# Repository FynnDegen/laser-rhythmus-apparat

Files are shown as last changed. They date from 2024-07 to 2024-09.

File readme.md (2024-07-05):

# laser-rhythmus-apparat (lra)

## Vorraussetzungen

- PortAudio

## Bauteile

- 1x Mikrokontroller (Arduino UNO R4 Minima):
https://store.arduino.cc/collections/boards-modules/products/uno-r4-minima

- 5x Lasersensoren (VL53L0X):
https://www.amazon.de/AZDelivery-VL53L0X-Flight-kompatibel-Arduino/dp/B086TSNTFD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

- Kabel (weiblich-weiblich, weiblich-männlich, männlich-männlich je 40x):
https://www.amazon.de/Female-Female-Male-Female-Male-Male-Steckbr%C3%BCcken-Drahtbr%C3%BCcken-bunt/dp/B01EV70C78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

- 2x Steckbretter:
https://www.amazon.de/VoltMate-Breadboard-Steckbrett-Kontakten-Kompatibel/dp/B0CX8MMN6T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

## Arduino

Falls ein Fehler auf Linux ubuntu auftreten sollte:

https://support.arduino.cc/hc/en-us/articles/9005041052444-Fix-udev-rules-on-Linux#renesas

Wie angegeben die post_install.sh Datei von GitHub herunterladen und im Verzeichnis der Datei das Terminal öffnen.

Dem .sh Skript Ausführungsrechte erteilen

```
chmod +x ./post_install.sh
```

Die Datei ausführen

```
sudo ./post_install.sh
```

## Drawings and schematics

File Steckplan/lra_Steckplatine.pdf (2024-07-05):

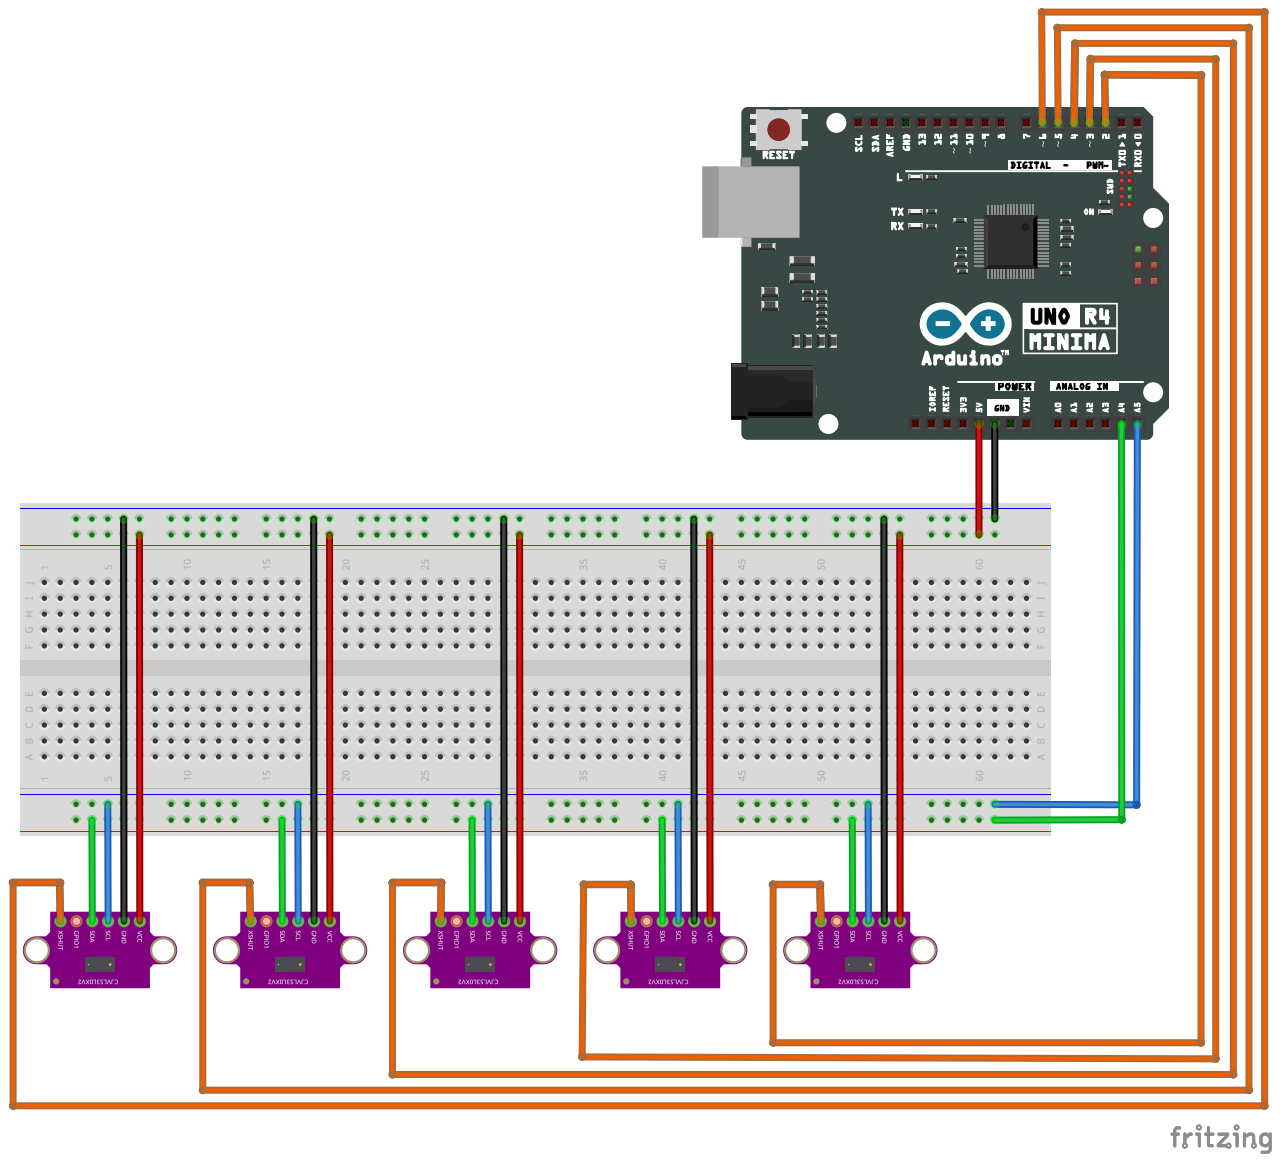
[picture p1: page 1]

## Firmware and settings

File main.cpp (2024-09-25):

#include <fcntl.h>
#include <termios.h>
#include <unistd.h>
#include <iostream>
#include <string.h>
#include <stdio.h>
#include <math.h>
#include <signal.h>
#include <random>

#include <portaudio.h>

#define MODE true

#define SAMPLE_RATE 44100
#define NUM_LASER 5

struct SineWaveData {
    double frequency = 0.0;
    double amplitude = 0.0;
    double phase = 0.0;
    bool isPlayed = false;
    short osc = 0;

    void increment() {
        phase += (2.0 * M_PI * frequency) / SAMPLE_RATE;
        if (phase >= 2.0 * M_PI) {
            phase -= 2.0 * M_PI;
        }
    }
};

int serialPort;

PaStream *stream;
SineWaveData data[NUM_LASER];

double oscillator(int oscNum, double phase) {
    switch(oscNum) {
        case 0:
            return sin(phase); // sine wave
        case 1:
            return (phase < 0.5) ? 0 : 1; // square wave
        case 2:
            return (2/M_PI)*asin(sin(phase)); // triangle wave
        case 3:
            return (cos(phase/2) < 0.0) ? (2/M_PI)*asin(sin(phase/2)) : (2/M_PI)*asin(cos((phase/2) - M_PI)); // sawtooth wave
        default:
            return 0.0;
    }
}

static int paCallback(const void *inputBuffer, void *outputBuffer, unsigned long framesPerBuffer, const PaStreamCallbackTimeInfo* timeInfo, PaStreamCallbackFlags statusFlags, void *userData) {
    float *out = (float*)outputBuffer;
    SineWaveData *data = (SineWaveData*)userData;
    
    for (unsigned long i = 0; i < framesPerBuffer; i++) {

        float audioOutput = 0;
        for(size_t i = 0; i < NUM_LASER; i++) {
            audioOutput += data[i].amplitude * oscillator(data[i].osc, data[i].phase);
        }
        audioOutput /= 3.75;
        *out++ = audioOutput;

        for(size_t i = 0; i < NUM_LASER; i++) {
            data[i].increment();
        }
    }
    return paContinue;
}

void checkErr(PaError err) {
    Pa_Terminate();
    std::cerr << "Fehler bei der Nutzung von PortAudio: " << Pa_GetErrorText(err) << std::endl;
    exit(-1);
}

int openSerialPort(const char* port) {
    int serialPort = open(port, O_RDONLY);

    if(serialPort < 0) {
        std::cerr << "Fehler beim Verbinden zum Arduino" << std::endl;
        exit(-1);
    }

    return serialPort;
}

void defaultMode() {

    data[0].frequency = 987.767; // h2
    data[1].frequency = 783.991; // g2
    data[2].frequency = 659.255; // e2
    data[3].frequency = 554.365; // cis2/des2
    data[4].frequency = 440.0;   // a1

    char read_buf[256];

    while(true) {
        memset(&read_buf, '\0', sizeof(read_buf));
        int num_bytes = read(serialPort, &read_buf, sizeof(read_buf));

        if(num_bytes < 0) {
            std::cerr << "Fehler beim Lesen vom Arduino" << std::endl;
            break;
        }

        std::string measurement = read_buf;
        if(measurement.find(":") != std::string::npos) {
            int laserIndex = measurement.at(1) - '0';
            int laser = std::stoi(measurement.substr(3));

            std::cout << laserIndex << " " << laser << std::endl;

            if(laser <= 720 && laser >= 60) {
                if(data[laserIndex].isPlayed) {
                    data[laserIndex].amplitude = std::max(0.5+((double)(rand() % 10)) / 100.0, data[laserIndex].amplitude-0.125);
                } else {
                    data[laserIndex].amplitude = 0.75;
                    data[laserIndex].isPlayed = true;
                }
            } else if((laser > 720 || laser < 60) && laser != 0) {
                data[laserIndex].amplitude = std::max(0.0, data[laserIndex].amplitude-0.075);
                data[laserIndex].isPlayed = false;
            }
        }
    }
}

void experimentalMode() {

    char read_buf[256];

    while(true) {
        memset(&read_buf, '\0', sizeof(read_buf));
        int num_bytes = read(serialPort, &read_buf, sizeof(read_buf));

        if(num_bytes < 0) {
            std::cerr << "Fehler beim Lesen vom Arduino" << std::endl;
            break;
        }

        std::string measurement = read_buf;
        if(measurement.find(":") != std::string::npos) {
            int laserIndex = measurement.at(1) - '0';
            int laser = std::stoi(measurement.substr(3));

            std::cout << laserIndex << " " << laser << std::endl;

            if(laser <= 720 && laser >= 60) {
                data[laserIndex].frequency = laser + 160;
            } else if((laser > 720 || laser < 60) && laser != 0) {
                data[laserIndex].frequency = 0;
            }
        }
    }
}

void signalHandler(int signum) {
    if(PaError err = Pa_StopStream(stream) != paNoError) {
        checkErr(err);
    }
    if(PaError err = Pa_CloseStream(stream) != paNoError) {
        checkErr(err);
    }
    if(PaError err = Pa_Terminate() != paNoError) {
        checkErr(err);
    }
    close(serialPort);
    std::cout << "\nLRA beendet" << std::endl;
    exit(0);
}

int main() {
    // Signal handler
    signal(SIGINT, signalHandler);

    // Serial port
    serialPort = openSerialPort("/dev/ttyACM0");

    //PortAudio
    if(PaError err = Pa_Initialize() != paNoError) {
        checkErr(err);
    }

    if( PaError err = Pa_OpenDefaultStream(&stream, 0, 1, paFloat32, SAMPLE_RATE, 256, paCallback, &data) != paNoError) {
        checkErr(err);
    }
    if(PaError err = Pa_StartStream(stream) != paNoError) {
        checkErr(err);
    }

    if(MODE) {
        defaultMode();
    } else {
        experimentalMode();
    }
}

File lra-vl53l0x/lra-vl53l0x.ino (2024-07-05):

#include "Adafruit_VL53L0X.h"

#define NUM_SENSORS 5

// address we will assign if dual sensor is present
const uint8_t LOX_ADDRESS[NUM_SENSORS] = {
    0x30, 0x31, 0x32, 0x33, 0x34
};

// set the pins to shutdown
const uint8_t SHT_LOX[NUM_SENSORS] = {
    2, 3, 4, 5, 6
};

// objects for the vl53l0x
Adafruit_VL53L0X lox[NUM_SENSORS];

// this holds the measurement
VL53L0X_RangingMeasurementData_t measure[NUM_SENSORS];

/*
    Reset all sensors by setting all of their XSHUT pins low for delay(10), then set all XSHUT high to bring out of reset
    Keep sensor #1 awake by keeping XSHUT pin high
    Put all other sensors into shutdown by pulling XSHUT pins low
    Initialize sensor #1 with lox.begin(new_i2c_address) Pick any number but 0x29 and it must be under 0x7F. Going with 0x30 to 0x3F is probably OK.
    Keep sensor #1 awake, and now bring sensor #2 out of reset by setting its XSHUT pin high.
    Initialize sensor #2 with lox.begin(new_i2c_address) Pick any number but 0x29 and whatever you set the first sensor to
 */
void setID() {
    // all reset
    for(int i = 0; i < NUM_SENSORS; i++) {
        digitalWrite(SHT_LOX[i], LOW);
    }
    delay(10);
    // all unreset
    for(int i = 0; i < NUM_SENSORS; i++) {
        digitalWrite(SHT_LOX[i], HIGH);
    }
    delay(10);

    // reset all
    for(int i = 0; i < NUM_SENSORS; i++) {
        digitalWrite(SHT_LOX[i], LOW);
    }
    delay(10);

    for(int i = 0; i < NUM_SENSORS; i++) {
        digitalWrite(SHT_LOX[i], HIGH);
        delay(10);

        if(!lox[i].begin(LOX_ADDRESS[i])) {
            Serial.println(F("Failed to boot VL53L0X"));
            while(1);
        }
        delay(10);
    }
}

void read_sensors() {

    for(int i = 0; i < NUM_SENSORS; i++) {
        lox[i].rangingTest(&measure[i], false);

        if(measure[i].RangeStatus != 4) {
            String str = ":" + String(i) + ":" + String(measure[i].RangeMilliMeter);
            Serial.print(str);
            Serial.println();
        } else {
            String str = ":" + String(i) + ":1";
            Serial.print(str);
            Serial.println();
        }
    }
}

void setup() {
    Serial.begin(115200);

    // wait until serial port opens for native USB devices
    while(! Serial) {
        delay(1);
    }

    for(int i = 0; i < NUM_SENSORS; i++) {
        pinMode(SHT_LOX[i], OUTPUT);
    }

    Serial.println(F("Shutdown pins inited..."));

    for(int i = 0; i < NUM_SENSORS; i++) {
        digitalWrite(SHT_LOX[i], LOW);
    }

    Serial.println(F("Both in reset mode...(pins are low)"));

    Serial.println(F("Starting..."));
    setID();
}

void loop() {
    read_sensors();
}

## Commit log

2024-05-28 lra für 1x Laser
2024-05-29 lra mit 2 Lasern
2024-06-11 Code refaktoriert & Distanz um 160mm verringert
2024-06-20 Arduino-Code um 3. Laser erweitert, Steckplan hinzugefügt
    [lra.fzz]
2024-06-26 Arduino Code mit 5 Lasern
2024-07-05 Standardmodus & Laser übermitteln RangeStatus 4
2024-09-25 lra v1.0.0 (#2)
    * openSerialPort() hinzugefügt
    * Refaktorierung, signalHandler()
    * audioOutput nun als additive Synthese
    * Hüllkurve hinzugefügt
    * Amplitudenrauschen
    * Oszillatoren
    * korrigierte Sägezahnwelle
    [main.cpp]
